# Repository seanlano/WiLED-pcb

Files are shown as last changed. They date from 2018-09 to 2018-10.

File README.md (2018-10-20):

# WiLED: PCB files

Circuit schematic and PCB for the WiLED main board, based on the ESP32 (ESP-WROOM-32) module. New version 3.0 of the board is an upgrade from the ESP8266-based version 1.0, but features improved layout and on-board LED driver components.

Schematic

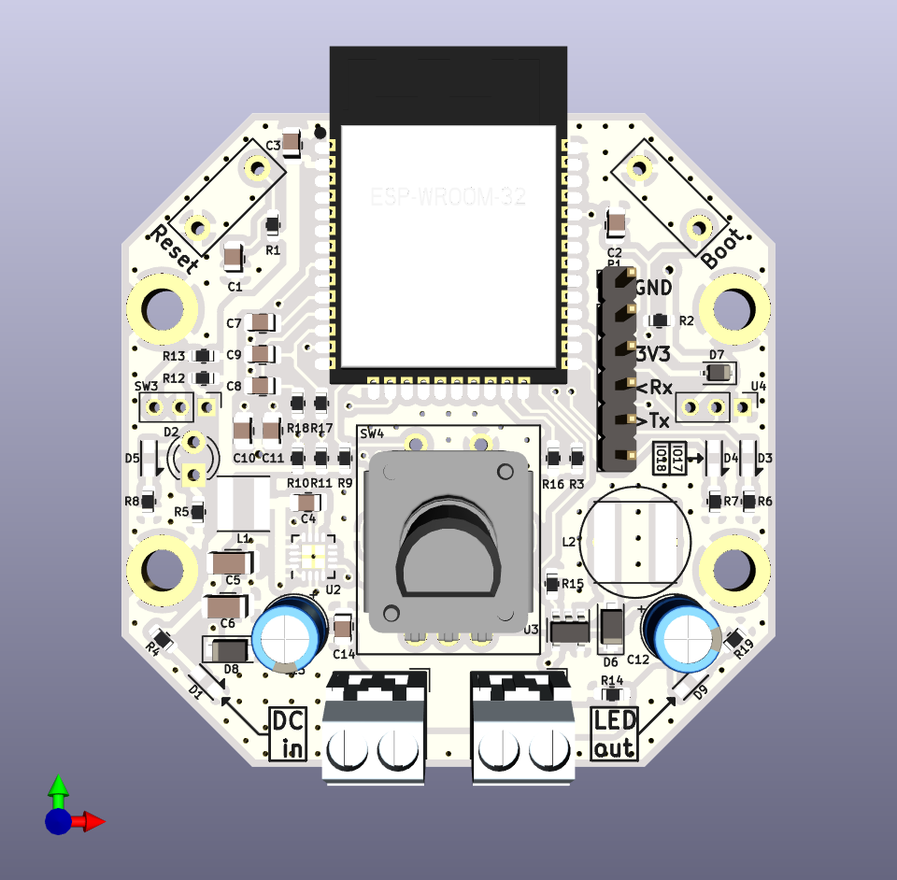
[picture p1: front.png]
Front of PCB


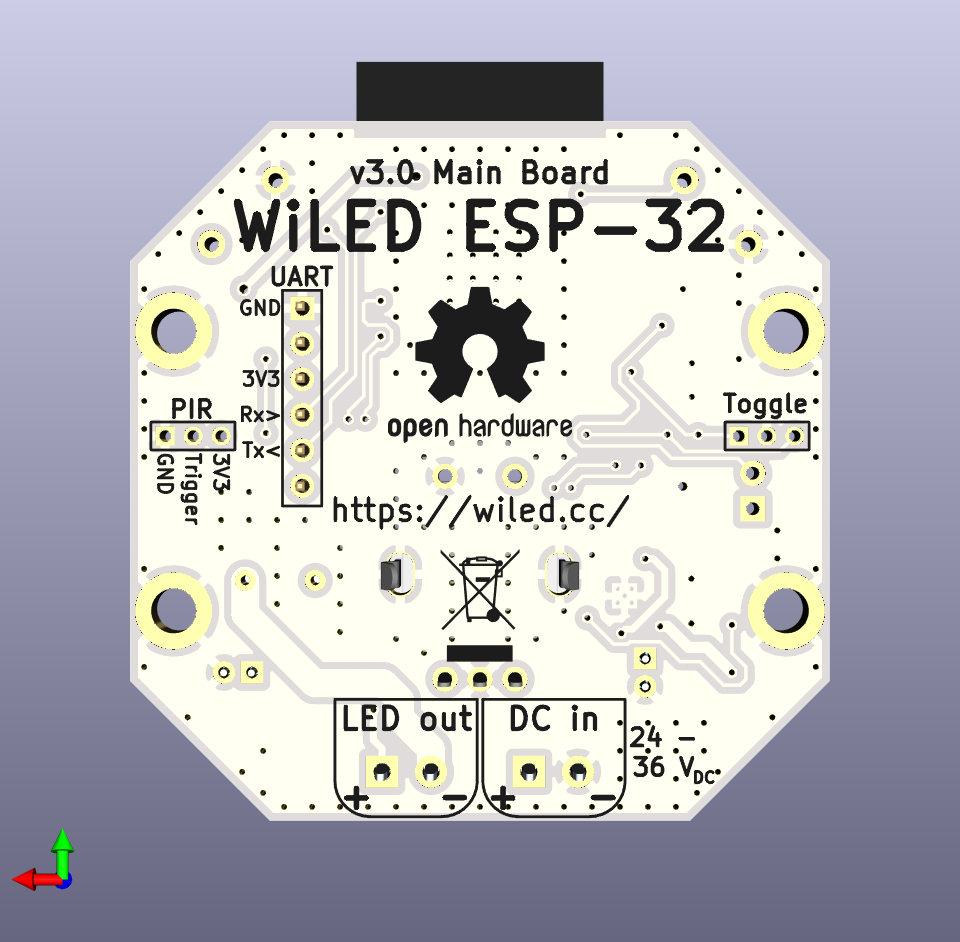
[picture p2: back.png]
Back of PCB


# Licence

All hardware schematics and design files are released under the CERN Open Hardware Licence v1.2. Please see [LICENCE](LICENCE) for details.

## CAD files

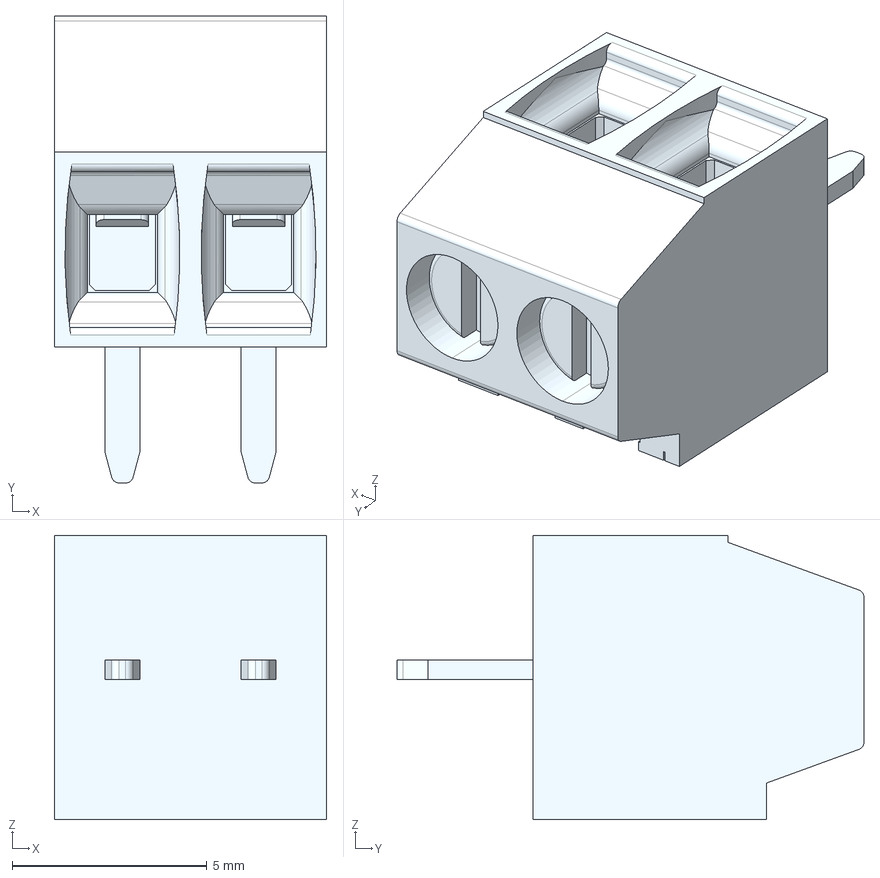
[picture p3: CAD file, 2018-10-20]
custom-footprints/terminal_c-1546551-2-a-3d.stp
7.00 x 12.0 x 7.30 mm

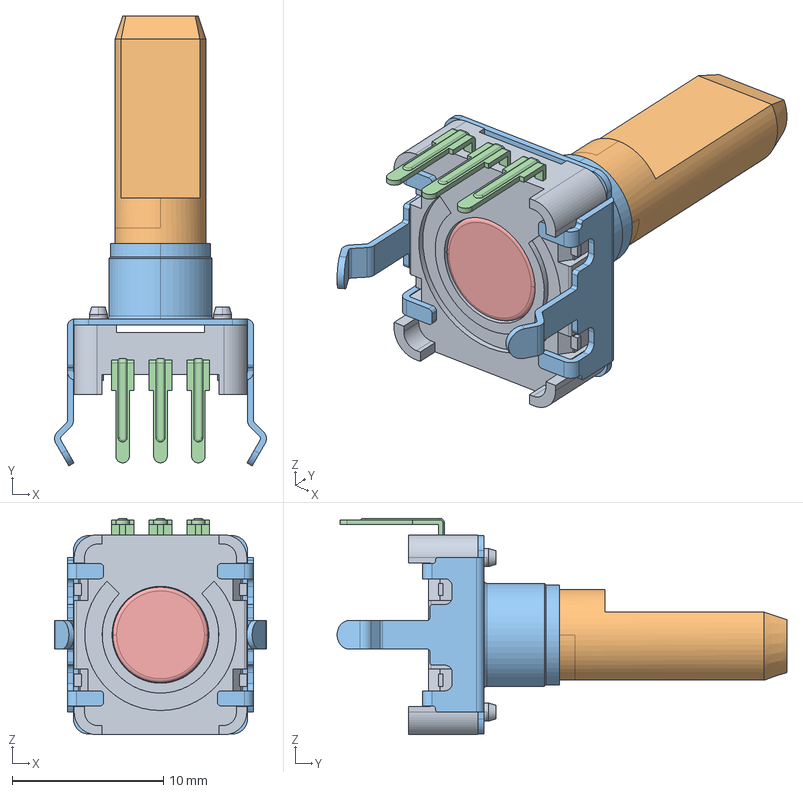
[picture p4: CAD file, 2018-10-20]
custom-footprints/pec12-4x25f-nxxxx.stp
14.0 x 29.7 x 14.3 mm
PEC12-BODY
PEC12-LID
PEC12-TERMINALS x 3
PEC12-ROTOR

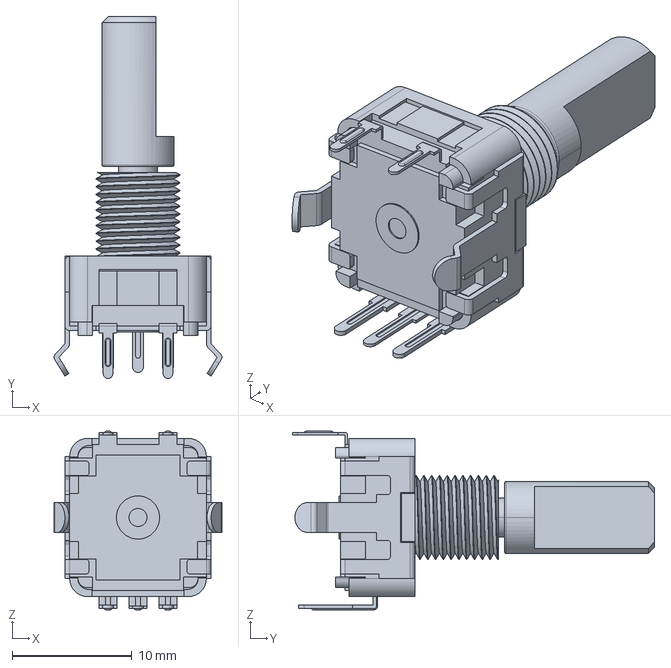
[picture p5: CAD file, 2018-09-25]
custom-footprints/pec11r-4x20f-sxxxx.stp
14.0 x 30.2 x 14.9 mm

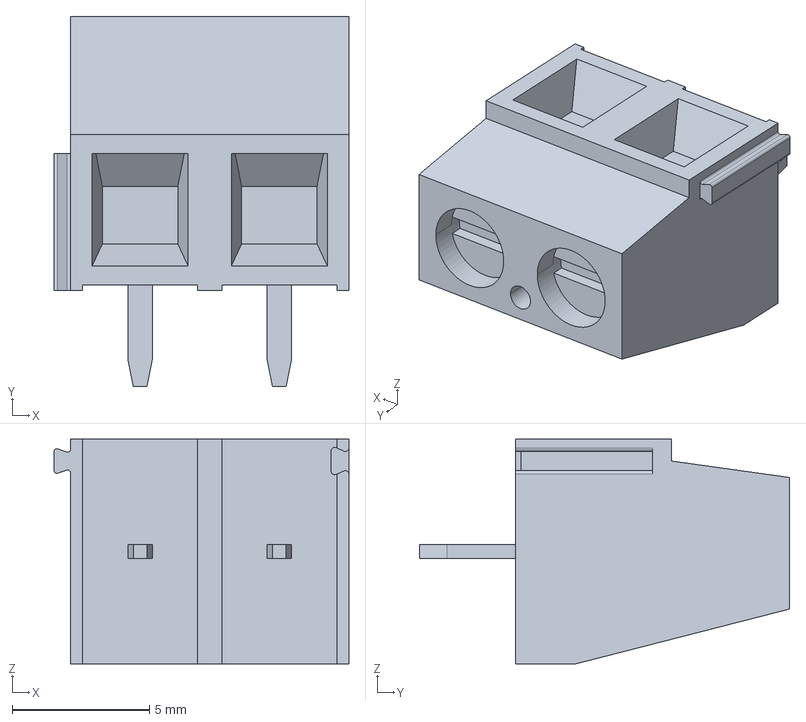
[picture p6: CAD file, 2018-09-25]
custom-footprints/terminal_c-282837-2-g2-3d.stp
10.8 x 13.5 x 8.20 mm

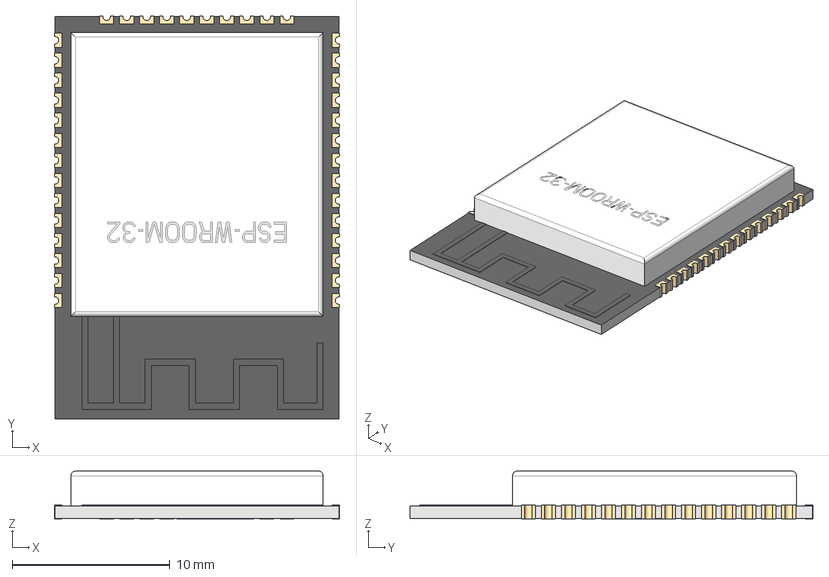
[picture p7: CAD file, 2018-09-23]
custom-footprints/ESP32-WROOM.step
18.1 x 25.5 x 3.04 mm

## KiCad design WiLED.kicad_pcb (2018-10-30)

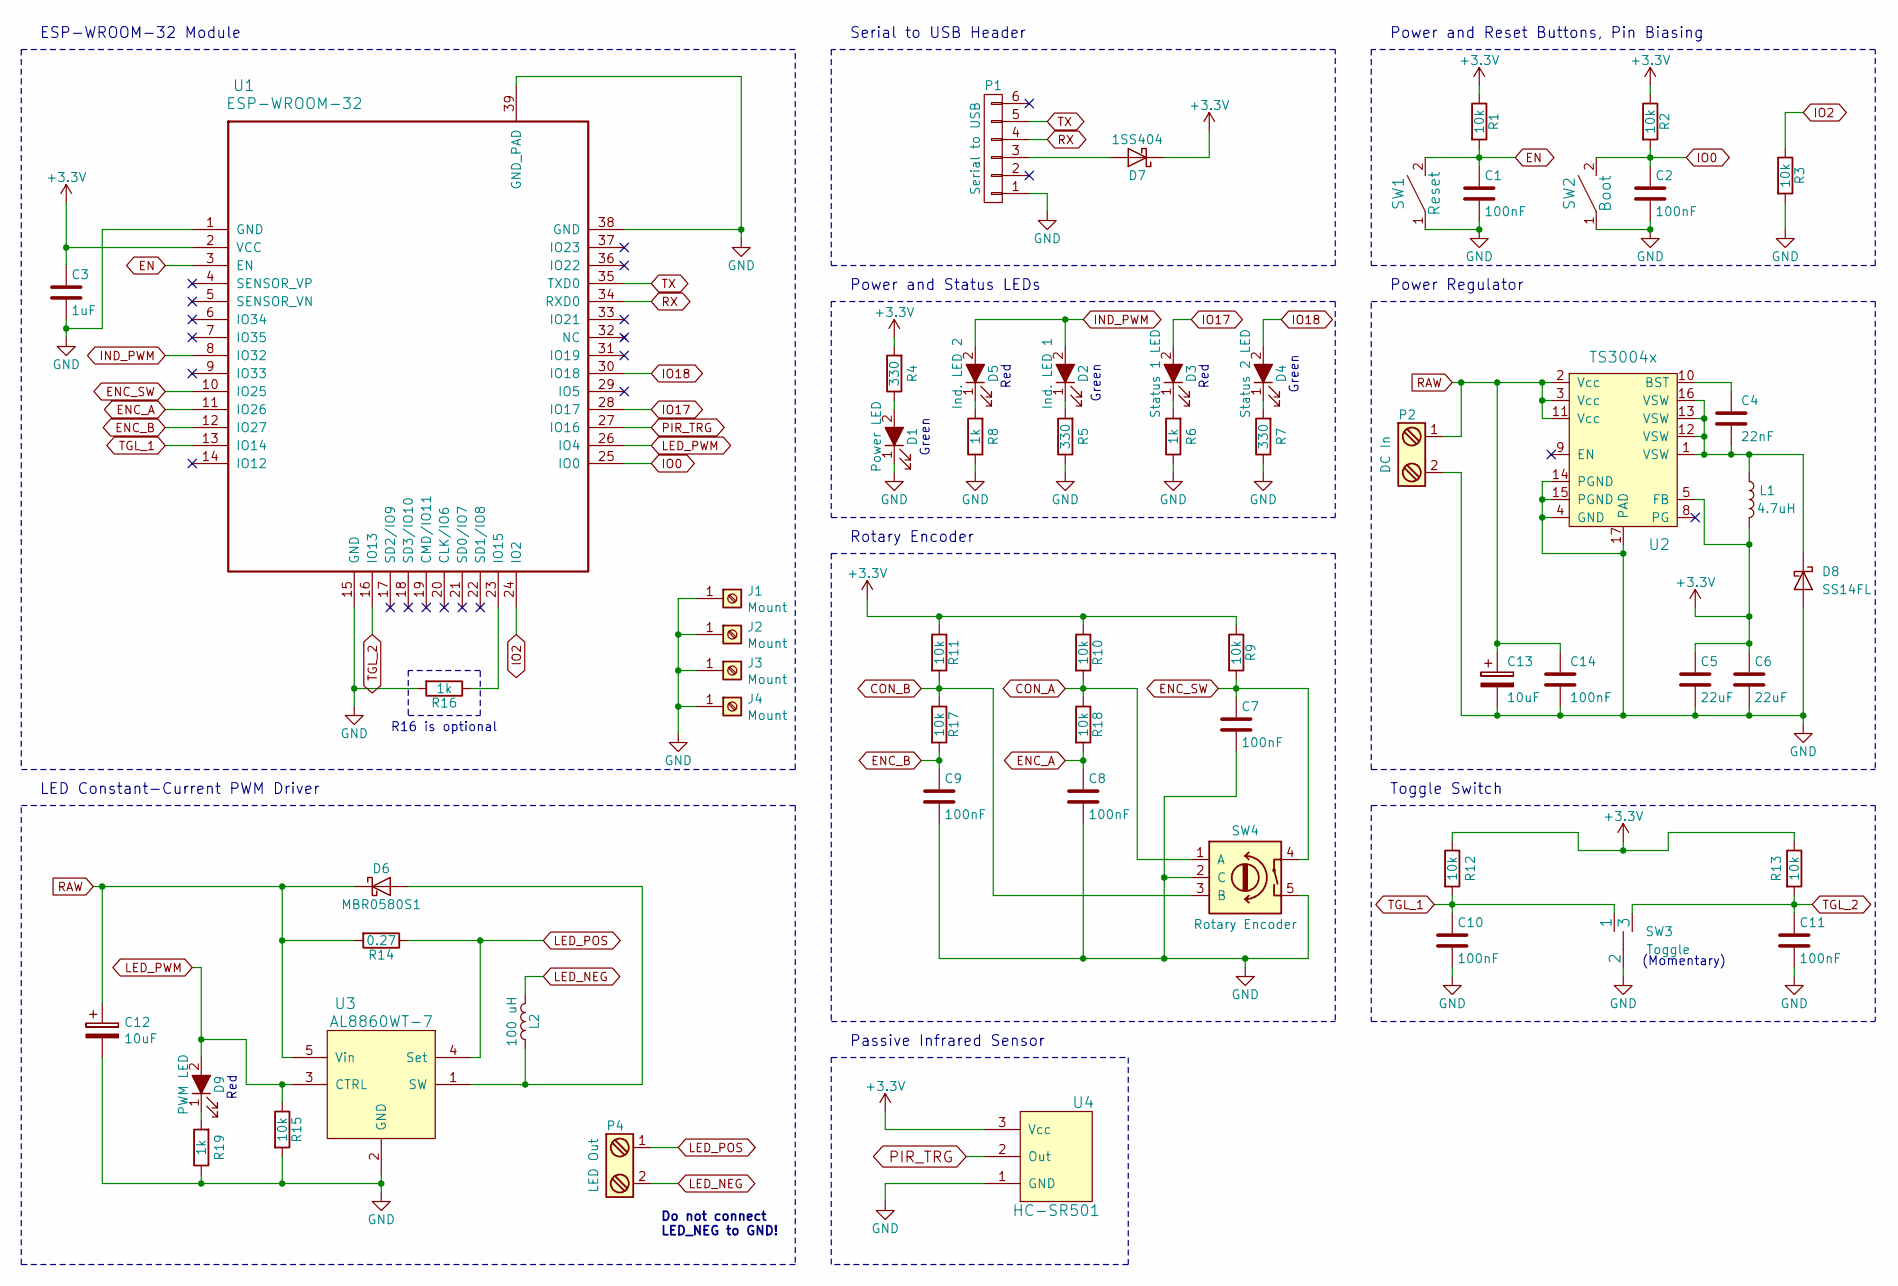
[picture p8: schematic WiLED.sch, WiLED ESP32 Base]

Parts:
C1, C2, C7, C8, C9, C10, C11, C14: 100nF; C_0805_2012Metric
C3: 1uF; C_0805_2012Metric
C4: 22nF; C_0805_2012Metric
C5, C6: 22uF; C_1206_3216Metric
C12, C13: 10uF
D1: Power LED; WL-SMCW
D2: Ind. LED 1; LED_D3.0mm
D3: Status 1 LED; WL-SMCW
D4: Status 2 LED; WL-SMCW
D5: Ind. LED 2; WL-SMCW
D6: MBR0580S1; D_SOD-123F
D7: 1SS404; D_SOD-323
D8: SS14FL; D_SOD-123F
D9: PWM LED; WL-SMCW
J1, J2, J3, J4: Mount; MountingHole_3.2mm_M3_ISO14580_Pad
L1: 4.7uH; L_Taiyo-Yuden_NR-40xx
L2: 100 uH; THT_Inductor_5mm
P1: Serial to USB; Pin_Header_Straight_1x06_Pitch2.54mm
P2: DC In; TerminalBlock_MetzConnect_Type059_RT06302HBWC_1x02_P3.50mm_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
P4: LED Out; TerminalBlock_MetzConnect_Type059_RT06302HBWC_1x02_P3.50mm_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
R1, R2, R3, R9, R10, R11, R12, R13, R15, R17, R18: 10k; R_0603_1608Metric
R4, R5, R7: 330; R_0603_1608Metric
R6, R8, R19: 1k; R_0603_1608Metric
R14: 0.27; R_0603_1608Metric_Pad1.05x0.95mm_HandSolder
R16: 1k; R_0603_1608Metric_Pad1.05x0.95mm_HandSolder
SW1: Reset; Button_6.5mm
SW2: Boot; Button_6.5mm
SW3: Toggle; Pin_Header_Straight_1x03_Pitch2.00mm
SW4: Rotary Encoder; PEC11R_5
U1: ESP-WROOM-32; ESP32-WROOM
U2: TS3004x; QFN-16-1EP_3x3mm_P0.5mm_EP2.7x2.7mm_ThermalVias
U3: AL8860WT-7; SOT-23-5
U4: HC-SR501; Pin_Header_Straight_1x03_Pitch2.00mm

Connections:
+3V3: C3.1, C5.1, C6.1, D7.1 (K), L1.2, R1.1, R2.1, R4.2, R9.1, R10.1, R11.1, R12.1, R13.1, U1.2 (VCC), U2.5 (FB), U4.3 (Vcc)
CON_A: R10.2, R18.1, SW4.1 (A)
CON_B: R11.2, R17.1, SW4.3 (B)
EN: C1.1, R1.2, SW1.2, U1.3 (EN)
ENC_A: C8.1, R18.2, U1.11 (IO26)
ENC_B: C9.1, R17.2, U1.12 (IO27)
ENC_SW: C7.1, R9.2, SW4.4, U1.10 (IO25)
GND: C1.2, C2.2, C3.2, C5.2, C6.2, C7.2, C8.2, C9.2, C10.2, C11.2, C12.2, C13.2, C14.2, D1.1 (K), D8.2 (A), J1.1, J2.1, J3.1, J4.1, P1.1, P2.2, R3.2, R5.1, R6.1, R7.1, R8.1, R15.2, R16.2, R19.1, SW1.1, SW2.1, SW3.2, SW4.2 (C), SW4.5, U1.1 (GND), U1.15 (GND), U1.38 (GND), U1.39 (GND_PAD), U2.4 (GND), U2.14 (PGND), U2.15 (PGND), U2.17 (PAD), U3.2 (GND), U4.1 (GND)
IND_PWM: D2.2 (A), D5.2 (A), U1.8 (IO32)
IO0: C2.1, R2.2, SW2.2, U1.25 (IO0)
IO2: R3.1, U1.24 (IO2)
IO17: D3.2 (A), U1.28 (IO17)
IO18: D4.2 (A), U1.30 (IO18)
LED_NEG: L2.2, P4.2
LED_POS: P4.1, R14.1, U3.4 (Set)
LED_PWM: D9.2 (A), R15.1, U1.26 (IO4), U3.3 (CTRL)
unnamed: C4.1, U2.10 (BST)
unnamed: C4.2, D8.1 (K), L1.1, U2.1 (VSW), U2.12 (VSW), U2.13 (VSW), U2.16 (VSW)
unnamed: D1.2 (A), R4.1
unnamed: D2.1 (K), R5.2
unnamed: D3.1 (K), R6.2
unnamed: D4.1 (K), R7.2
unnamed: D5.1 (K), R8.2
unnamed: D6.2 (A), L2.1, U3.1 (SW)
unnamed: D7.2 (A), P1.3
unnamed: D9.1 (K), R19.2
unnamed: R16.1, U1.23 (IO15)
PIR_TRG: U1.27 (IO16), U4.2 (Out)
RAW: C12.1, C13.1, C14.1, D6.1 (K), P2.1, R14.2, U2.2 (Vcc), U2.3 (Vcc), U2.11 (Vcc), U3.5 (Vin)
RX: P1.4, U1.34 (RXD0)
TGL_1: C10.1, R12.2, SW3.1, U1.13 (IO14)
TGL_2: C11.1, R13.2, SW3.3, U1.16 (IO13)
TX: P1.5, U1.35 (TXD0)

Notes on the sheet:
Power Regulator
Rotary Encoder
Serial to USB Header
Power and Status LEDs
Green
Power and Reset Buttons, Pin Biasing
ESP-WROOM-32 Module
Red
LED Constant-Current PWM Driver
Toggle Switch
(Momentary)
Do not connect LED_NEG to GND!
R16 is optional
Passive Infrared Sensor

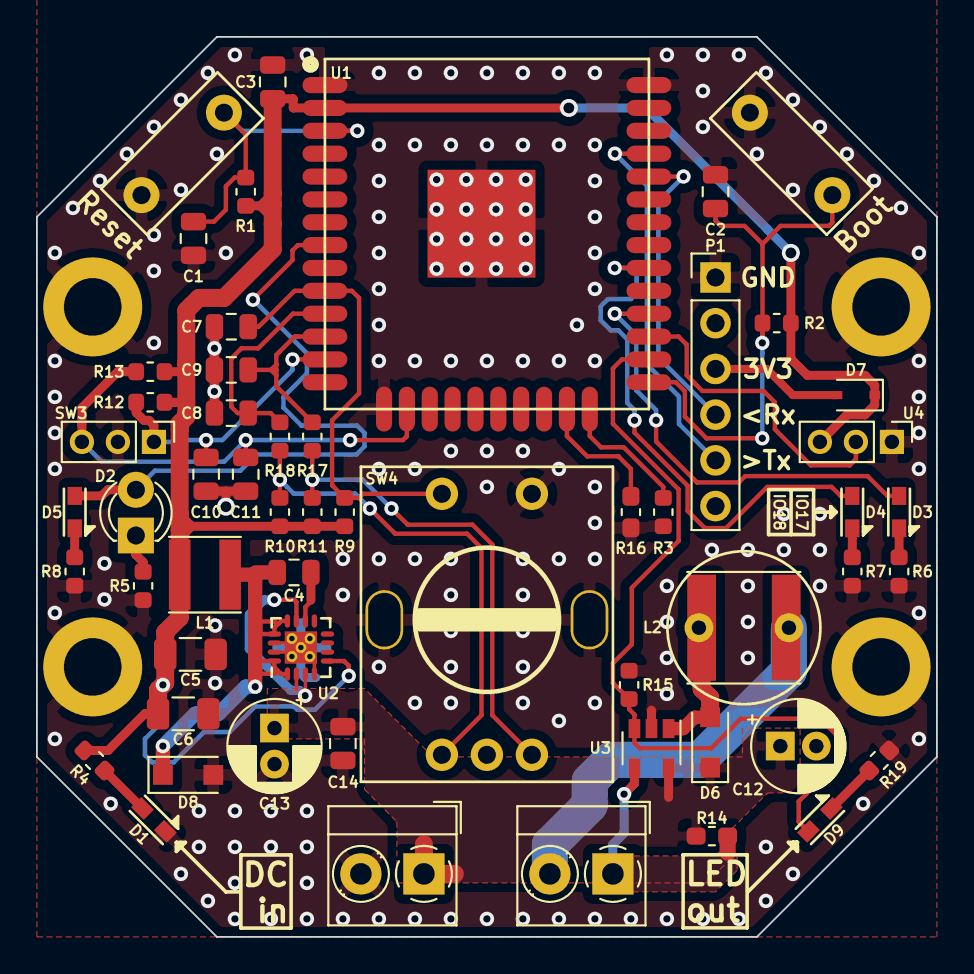
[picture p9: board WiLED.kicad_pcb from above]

Board: 2 copper layers, 50.0 x 50.0 mm, 59 parts (0 on the bottom side), 33 nets.

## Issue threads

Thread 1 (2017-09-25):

No pull-down on LED_PWM line

seanlano, 2017-09-25:
`LED_PWM` needs a pull-down to ground, so that when the EPS8266 resets the LED driver is pulled low. When left out, the driver sees a high impedance and drives its output at full power.

Closed 2017-09-25.

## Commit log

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2017-09-10 Removed auto-reset circuit
    [WiLED.sch]
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2017-09-11 Change LED_PWM and IND_PWM for better routing
    [WiLED.sch]
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2017-09-12 Finalised first draft of PCB
    [WiLED.kicad_pcb, WiLED.sch]
2017-09-12 Second draft of PCB
    [WiLED.kicad_pcb, WiLED.sch]
2017-09-13 Update board edge and drill sizes
    [WiLED.kicad_pcb]
2017-09-18 Remove EN from DIO1 pin on Feather header
    [WiLED.kicad_pcb, WiLED.sch]
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2017-09-18 Fix button labels on PCB
    [WiLED.kicad_pcb]
2017-09-18 Update PCB for plotting to Gerber
    [WiLED.kicad_pcb]
2017-09-25 Add pull-down on LED_PWM. Closes #1
    [WiLED.sch]
2018-06-22 Update schematic to Version 2.0, using the ESP-WROOM-32
    [WiLED.kicad_pcb, WiLED.sch]
2018-07-01 First draft of v2.0 schematic and PCB
    This is the first complete schematic and PCB layout for version 2.0 of
    the WiLED main board. Some tweaks may be needed, but the general concept
    is complete.
    [WiLED.kicad_pcb, WiLED.sch]
2018-07-01 Add ground copper pours
    [WiLED.kicad_pcb]
2018-07-02 Increase via size and mounting hole size
    Vias were 0.4/0.6 mm, this has been increased to 0.4/0.8 mm to make
    manufacturing a little easier - and there's no reason to need the
    smaller size.
    The mounting holes were M2.5 size, but changed this to M3 for slightly
    more standard screw fittings.
    [WiLED.kicad_pcb]
2018-07-02 Rework LED constant-current PCB layout
    Previously there were unnecssarily long traces between high-power
    components in the buck-mode LED driver, this commit brings a modified
    layout that tries to improve on this.
    [WiLED.kicad_pcb, WiLED.sch]
2018-07-03 Tidy up board outline and improve ground planes
    Revised the board outline to make it a nice metric multiple.
    Also rerouted some traces to give a more contiguous ground plane.
    [WiLED.kicad_pcb]
2018-07-04 Add stitching vias to PCB
    The PCB now has numerous stitching vias for the ground planes.
    Also made some of the silk screen text slightly larger.
    [WiLED.kicad_pcb]
2018-07-08 Add PIR sensor and more stitching vias
    Added a connection for a HC-SR501 PIR sensor, to a spare GPIO on the
    ESP-32.
    Also increased the number of stitching vias.
    [WiLED.kicad_pcb, WiLED.sch]
2018-07-08 Add OSHW logo to silkscreen
    [WiLED.kicad_pcb]
2018-07-09 Add input voltage to silkscreen
    [WiLED.kicad_pcb]
2018-08-05 Correct pin mappings from unusable ESP32 pins
    Some LED indicators were assigned to ESP32 pins which are only available
    for input, and the toggle switch was mapped to the MTDO pin. Both of
    these mistakes are corrected in this commit.
    [WiLED.sch]
2018-08-22 Update PCB for KiCad 5, and begin rerouting for new PSU
    [WiLED.kicad_pcb, WiLED.sch]
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2018-08-22 Initial complete routing of PCB for v2.1
    [WiLED.kicad_pcb]
2018-09-01 Completed PCB routing
    Routing is complete, although there is quite some wasted space on the
    board - so a re-think is in order to further shrink the size of the
    board.
    [WiLED-2018-07-30-21-47-28.sch]
2018-09-01 Re-designed layout, with less wasted space
    Routing is completed, but vias still need to be added. The newer layout
    is much more space efficient.
    [WiLED.kicad_pcb, WiLED.sch]
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2018-09-12 Move lower section components down slightly
    There is still a little bit more tightening that can be done vertically
    on the PCB layout. Some of the components on the lower part of the board
    have been moved down, to make space to move other components into.
    The PCB width is acceptable, but reducing the height would be ideal.
    [WiLED.kicad_pcb]
2018-09-14 Move top components down, shorten board height
    [WiLED.kicad_pcb]
2018-09-15 Re-do layout, for v3.0
    Having started the 3D CAD for the enclosure, it seems that the PCB is
    able to be slightly wider than previously planned. To make the most of
    this new width, a complete rearrange has been done - the PCB is now a
    square shape.
    Routing has been completed on this new layout, vias still need to be
    added.
    [WiLED.kicad_pcb, WiLED.sch]
2018-09-16 Add stiching vias
    Ground plane stitching vias have been added.
    [WiLED.kicad_pcb]
2018-09-23 Finalise v3.0 layout, add ESP32 3D model
    Layout is now complete for the v3.0 board, pending a review. Stitching
    vias are in place, and silkscreen has been updated.
    Also added a 3D model for the ESP32, to help with modelling the
    enclosure.
    [ESP32-WROOM.step, WiLED.kicad_pcb, WiLED.sch]
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2018-09-25 Update 3D models for terminal block and encoder
    Found some manufacturer-supplied 3D models for the rotary encoder and
    the terminal block, so added these to the PCB.
    [WiLED.kicad_pcb, pec11r-4x20f-sxxxx.stp, terminal_c-282837-2-g2-3d.stp]
2018-10-02 Change R14 to 0603 size
    R14 was originally an 0603 in v1.0, but was changed to an 0805 - looking
    at parts, 0603 are cheaper and still have the required values and
    tolerances, so 0603 should be used instead.
    [WiLED.kicad_pcb, WiLED.sch]
2018-10-08 Change C12 and C13 to through-hole electrolytic caps
    C12 and C13 were initially MLCCs, but these are harder to obtain and are
    more expensive than electrolytics - for this use case, the swap should
    be acceptable.
    [WiLED.kicad_pcb, WiLED.sch]
2018-10-09 Nudge C12 and C13 down slightly
    Moved C12 and C13 down, to make slightly more space for the screw when
    fitted into the mounting hole.
    [WiLED.kicad_pcb]
2018-10-10 Update model for pin headers, revise ground vias
    Updated the footprint for the 6-pin header P1, to one with a 3D model.
    Revised some ground plane vias, and re-routed some tracks to give
    slightly more contiguous ground plane regions.
    [WiLED.kicad_pcb, WiLED.sch]
2018-10-17 Change terminal blocks to 3.5 mm type
    The previous terminal blocks were the 5.08 mm type, which are quite
    large - larger than is needed. The 3.5 mm type should be enough, so
    changed the footprints and re-routed where needed.
    [WiLED.kicad_pcb, WiLED.sch]
2018-10-20 Update 3D models for screw terminal and rotary encoder
    [WiLED.kicad_pcb, pec12-4x25f-nxxxx.stp, terminal_c-1546551-2-a-3d.stp]
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2018-10-29 Minor PCB tweaks
    As suggested by Oliver, made the following tweaks:
    - Added a keepout on the ground pour around L1
    - Made the small trace for the LED terminal block larger
    - Added a few arrows and a couple of labels for the LEDs
    [WiLED.kicad_pcb]
2018-10-30 Update drill hole sizes
    Rationalise a few drill hole sizes, to make manufacturing slightly
    easier.
    [WiLED.kicad_pcb]
